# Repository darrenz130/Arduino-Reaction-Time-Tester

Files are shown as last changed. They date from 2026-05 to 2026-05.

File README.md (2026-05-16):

<h1>Arduino Reaction Time Tester PCB Design</h1>

<h2>Overview</h2>

<p>
This project is an Arduino-based reaction time testing system designed to measure human response speed with millisecond accuracy. The system uses LEDs as visual stimuli, a push button for user input, and a display to show reaction time results. The firmware is written in C++ and implemented on a custom PCB designed in KiCad.
</p>

<h2>Project Walkthrough</h2>

<h3>1. Breadboard Prototype</h3>

<p>
The initial version of the circuit was built and tested on a breadboard to validate functionality. This phase focused on verifying LED triggering, button input detection, and reaction timing accuracy.
</p>

<h3>2. Firmware Development</h3>

<p>
The system was programmed in C++ using the Arduino IDE. The code handles randomized LED stimulus timing, button press detection, and calculates reaction time in milliseconds using precise timing functions.
</p>

<h3>3. Schematic Design</h3>

<p>
A full circuit schematic was created in KiCad to define the electrical connections between the Arduino, LEDs, button, and display.
</p>

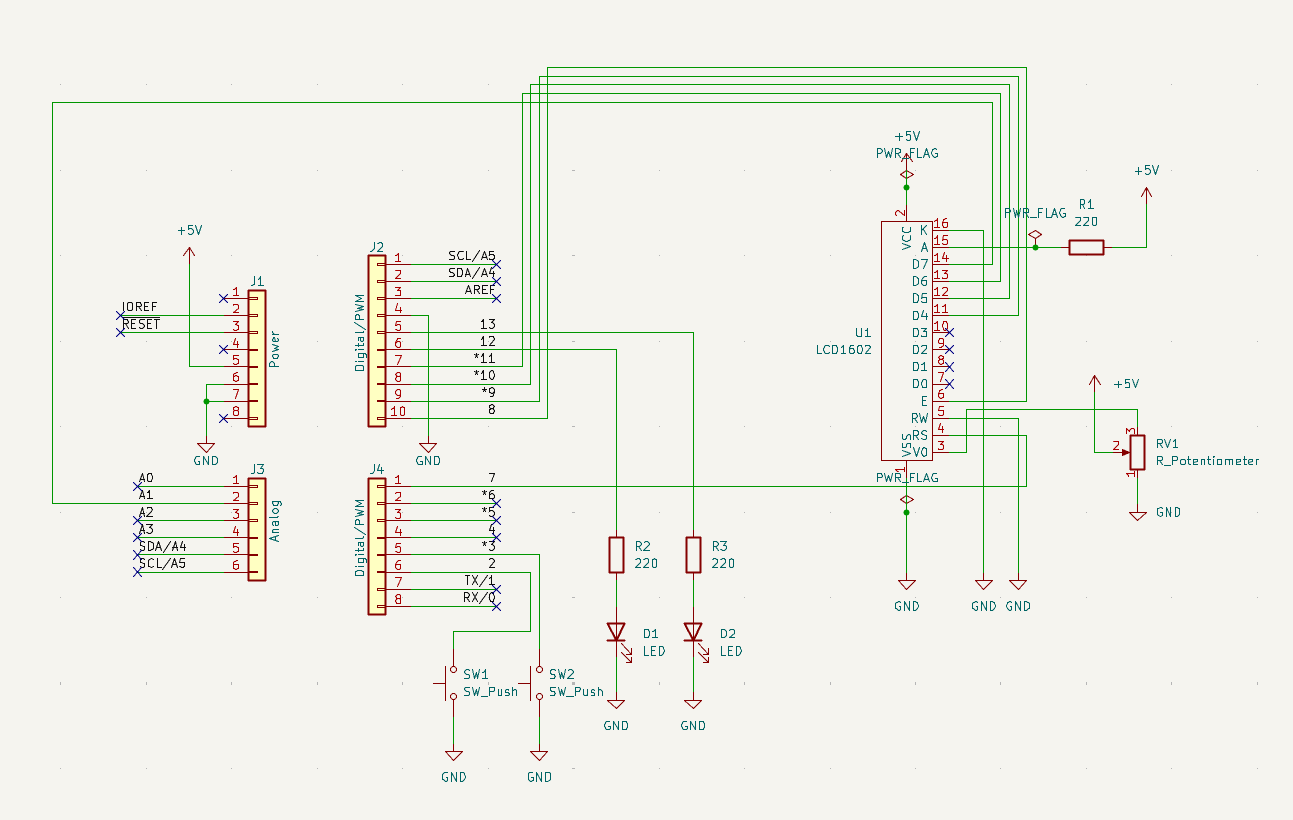
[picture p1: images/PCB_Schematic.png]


<h3>4. PCB Design</h3>

<p>
A custom PCB shield was designed in KiCad to replace the breadboard setup. This reduced wiring complexity, improved reliability, and created a compact final hardware design.
</p>

<p>
Custom footprints were created where required to match exact component dimensions. This included a potentiometer footprint due to the lack of an existing library part with the correct physical spacing, as well as a custom footprint for the display LED to ensure proper fit and alignment.
</p>

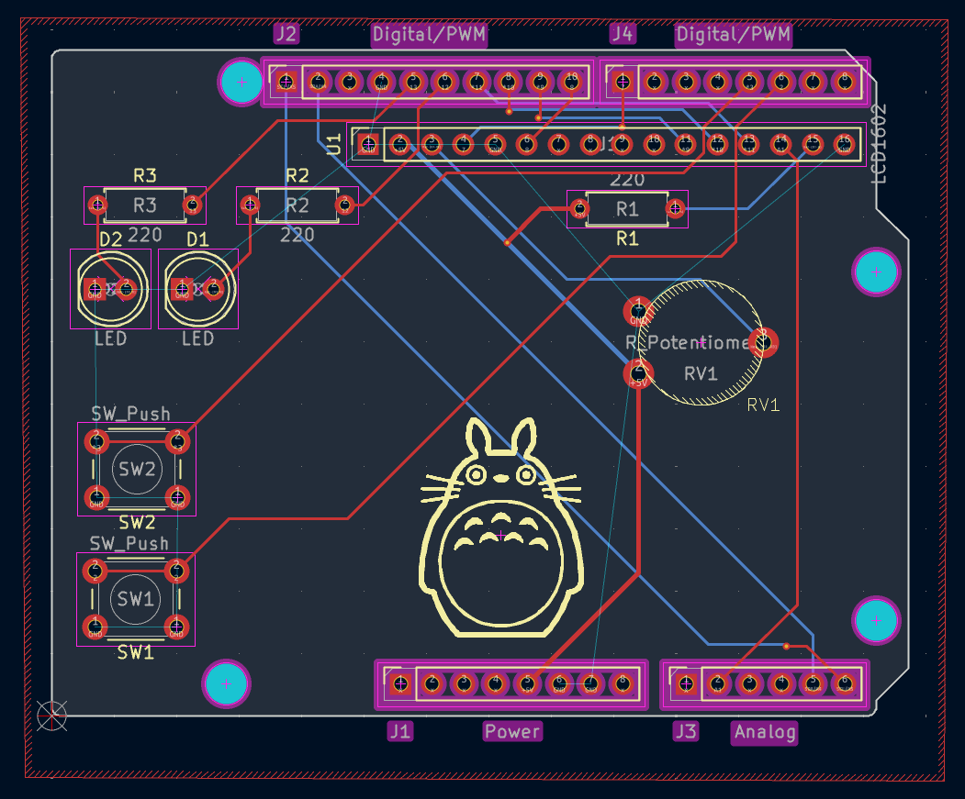
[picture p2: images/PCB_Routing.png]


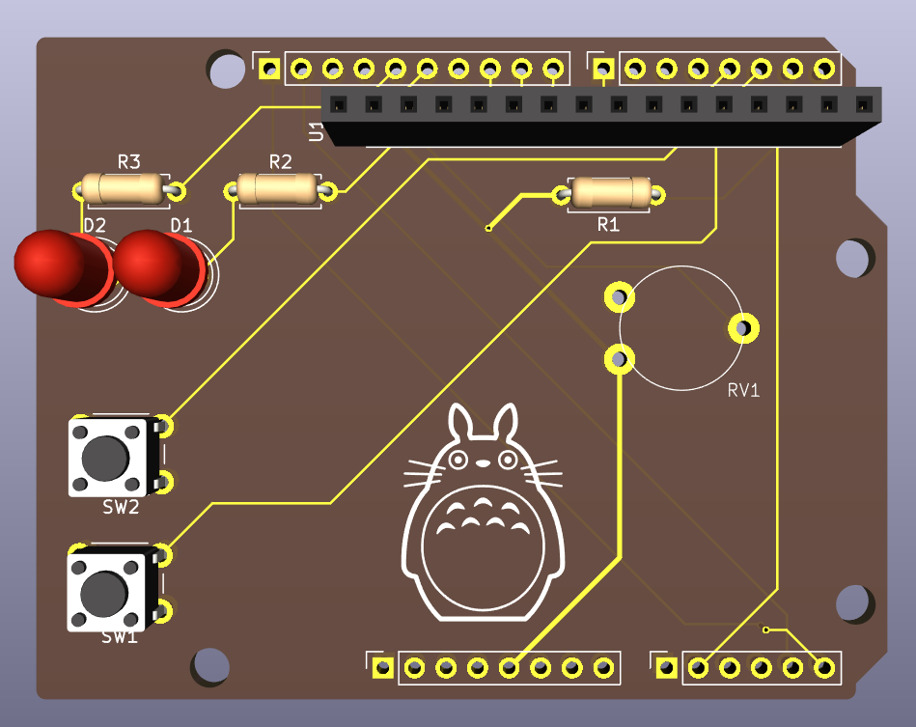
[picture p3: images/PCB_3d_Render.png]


<h2>Languages and Tools Used</h2>

<ul>
  <li>C++</li>
  <li>Arduino IDE</li>
  <li>KiCad (PCB Design)</li>
  <li>Breadboard Prototyping</li>
  <li>Multimeter / Circuit Debugging</li>
</ul>

<h2>Files in This Repository</h2>

<ul>
  <li><b>/firmware</b> → Arduino C++ code</li>
  <li><b>/pcb</b> → KiCad schematic and PCB files</li>
  <li><b>/images</b> → Project screenshots and renders</li>
</ul>

<h2>Demo</h2>

<p>
A short demonstration of the system in action:
<br>
<a href="https://youtu.be/OleBV9ndicw?si=QzNY1ve2LQjAxAnz">
Watch Demo Video
</a>
</p>

<h2>Key Features</h2>

<ul>
  <li>Millisecond-level reaction time measurement</li>
  <li>Randomized LED stimulus timing</li>
  <li>Custom PCB shield for improved reliability</li>
  <li>Fully tested breadboard prototype before final design</li>
</ul>

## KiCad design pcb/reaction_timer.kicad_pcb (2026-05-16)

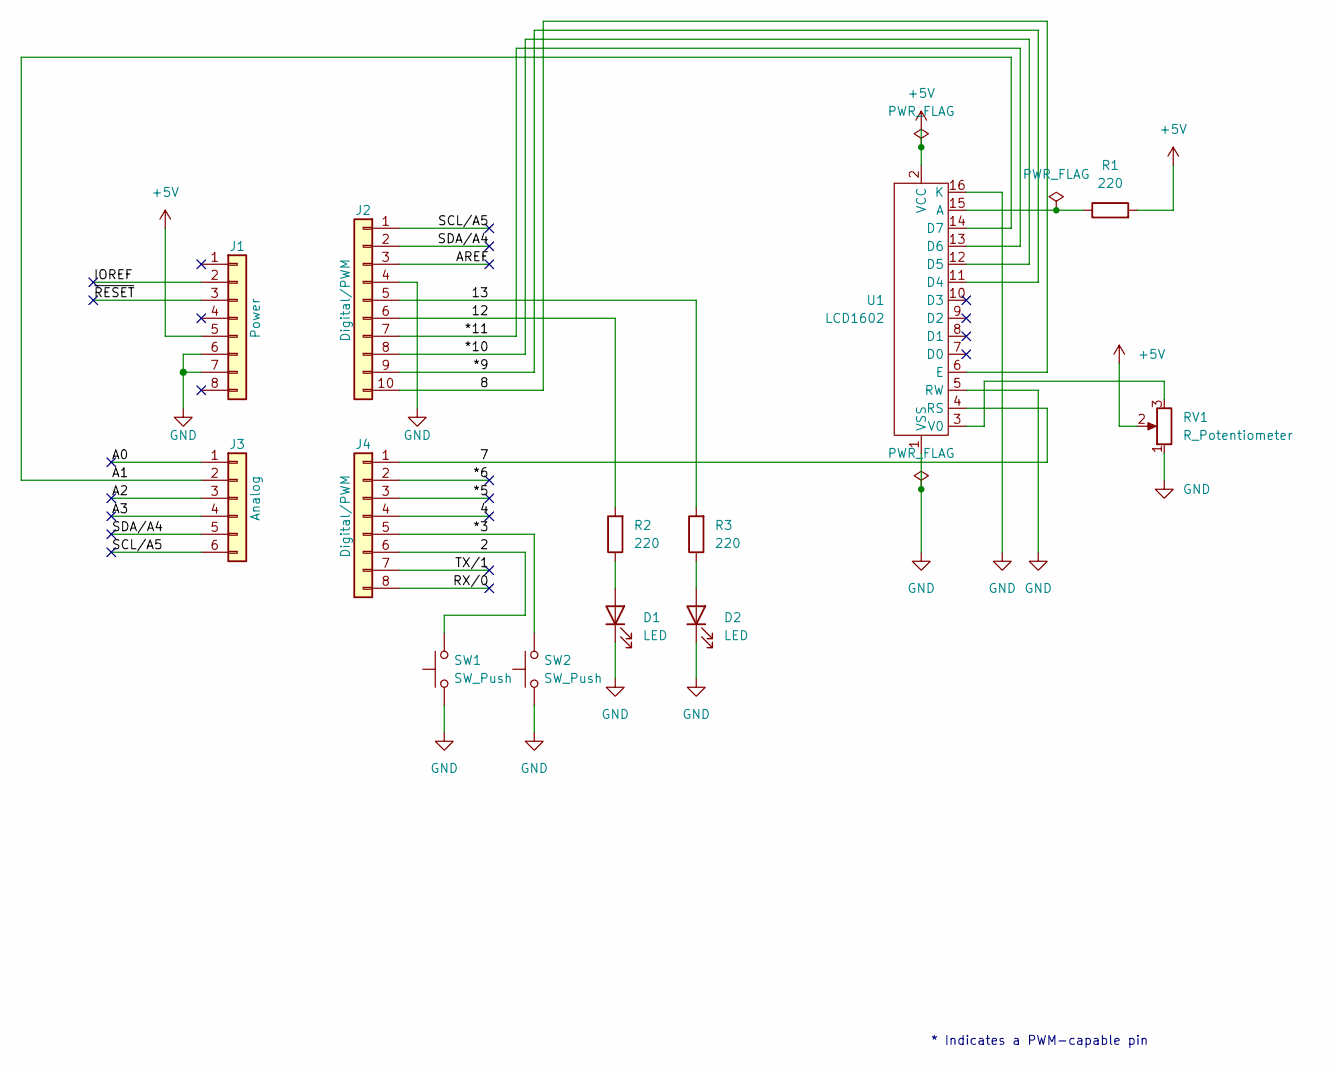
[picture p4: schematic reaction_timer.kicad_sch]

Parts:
D1, D2: LED; LED_D5.0mm
J1: Power; PinSocket_1x08_P2.54mm_Vertical
J2: Digital/PWM; PinSocket_1x10_P2.54mm_Vertical
J3: Analog; PinSocket_1x06_P2.54mm_Vertical
J4: Digital/PWM; PinSocket_1x08_P2.54mm_Vertical
R1, R2, R3: 220; R_Axial_DIN0207_L6.3mm_D2.5mm_P7.62mm_Horizontal
RV1: R_Potentiometer; 10k potentiameter
SW1, SW2: SW_Push; SW_PUSH_6mm
U1: LCD1602; PinSocket_1x16_P2.54mm_Vertical

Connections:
+5V: J1.5, R1.2, RV1.2, U1.2 (VCC)
/2: J4.6, SW1.2
/4: J4.4
/7: J4.1, U1.4 (RS)
/8: J2.10, U1.6 (E)
/12: J2.6, R2.2
/13: J2.5, R3.2
/*3: J4.5, SW2.2
/*5: J4.3
/*6: J4.2
/*9: J2.9, U1.11 (D4)
/*10: J2.8, U1.12 (D5)
/*11: J2.7, U1.13 (D6)
/A0: J3.1
/A1: J3.2, U1.14 (D7)
/A2: J3.3
/A3: J3.4
/AREF: J2.3
/IOREF: J1.2
/RX/0: J4.8
/SCL/A5: J2.1, J3.6
/SDA/A4: J2.2, J3.5
/TX/1: J4.7
/~RESET: J1.3
GND: D1.1 (K), D2.1 (K), J1.6, J1.7, J2.4, RV1.1, SW1.1, SW2.1, U1.1 (VSS), U1.5 (RW), U1.16 (K)
unnamed: D1.2 (A), R2.1
unnamed: D2.2 (A), R3.1
unnamed: R1.1, U1.15 (A)
unnamed: RV1.3, U1.3 (V0)

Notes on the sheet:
* Indicates a PWM-capable pin

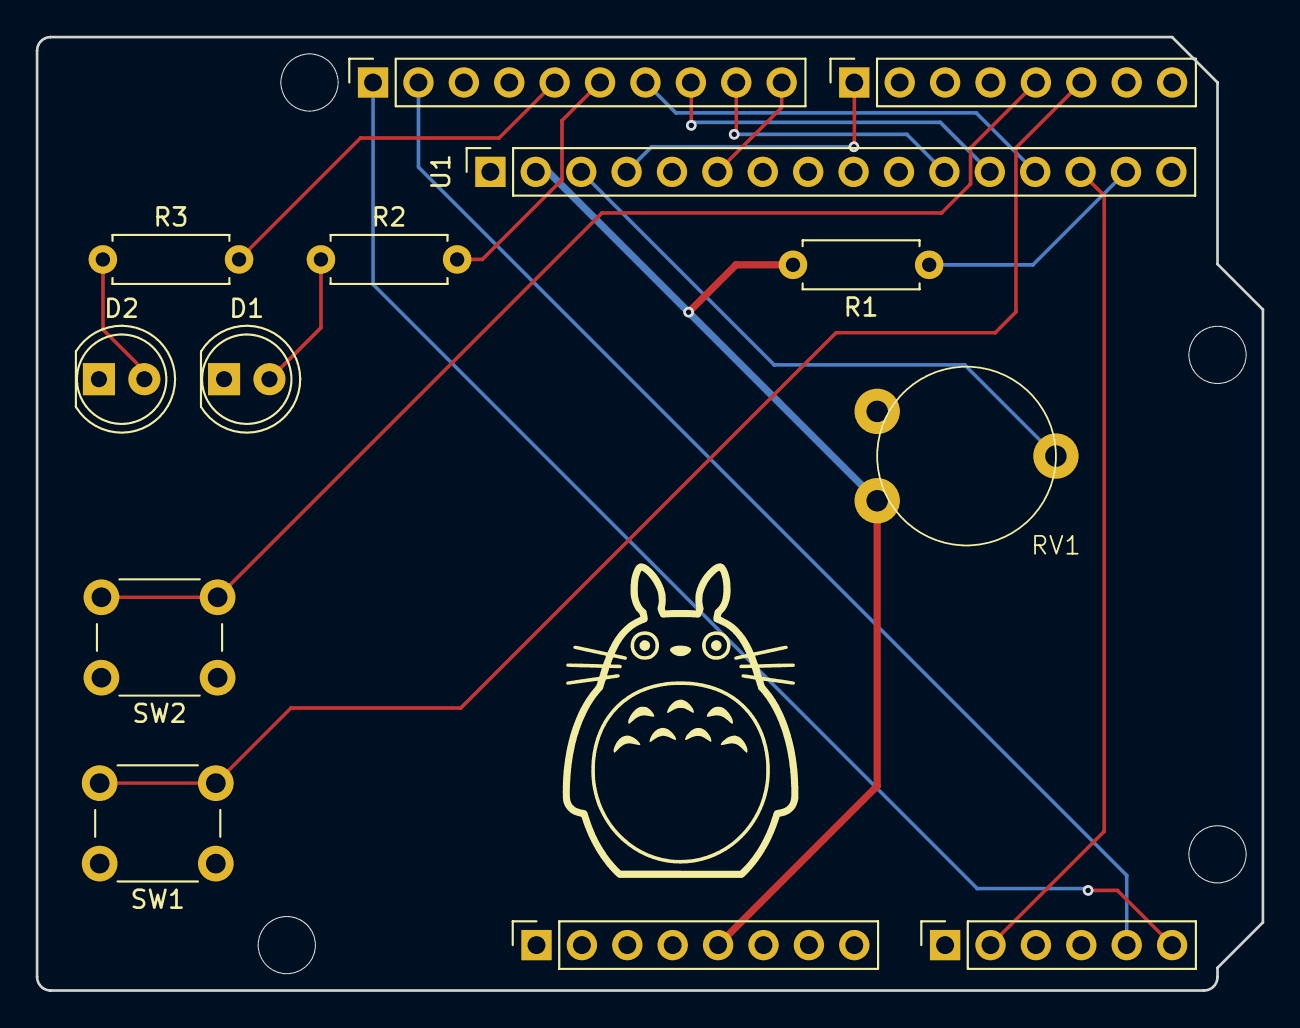
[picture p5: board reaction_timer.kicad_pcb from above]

Board: 2 copper layers, 68.6 x 53.3 mm, 17 parts (0 on the bottom side), 18 nets.

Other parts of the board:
MH1, MH2, MH3, MH4: MountingHole_3.2mm

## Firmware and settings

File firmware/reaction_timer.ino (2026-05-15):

#include <LiquidCrystal.h>

// LCD pins: RS, E, D4, D5, D6, D7
LiquidCrystal lcd(7, 8, 9, 10, 11, A1);

const int led_green = 13;
const int led_red = 12;
const int startButton = 2; 
const int clickButton = 3; 

unsigned long waitTime = 0;
unsigned long startTime = 0;
unsigned long reactionTime = 0;

// Define states
enum State {IDLE, WAITING, GREEN_ON, DONE};
State currentState = IDLE;

void setup() {
  pinMode(led_green, OUTPUT);
  pinMode(led_red, OUTPUT);
  pinMode(startButton, INPUT_PULLUP);
  pinMode(clickButton, INPUT_PULLUP);

  lcd.begin(16, 2);
  lcd.setCursor(0,0);
  lcd.print("Reaction Timer");
  lcd.setCursor(0,1);
  lcd.print("Press Start");
  
  randomSeed(analogRead(A0));
}

void loop() {  
  switch(currentState) {
    case IDLE:
      // Wait for start button to begin
      if (digitalRead(startButton) == LOW) {
        lcd.setCursor(0,1);
        lcd.print("Get Ready...   ");
        digitalWrite(led_red, HIGH);
        waitTime = random(1000, 5000); // 1-5 sec
        startTime = millis();
        currentState = WAITING;
        delay(50); // debounce
      }
      break;

    case WAITING:
      if(digitalRead(led_red) == HIGH && digitalRead(clickButton) == LOW){
        digitalWrite(led_red, LOW);
        lcd.setCursor(0,1);
        lcd.print("Too Early!     ");
        currentState = DONE;
        delay(200);
      }
      if (millis() - startTime >= waitTime) {
        digitalWrite(led_red, LOW);
        digitalWrite(led_green, HIGH); // stays on until click
        lcd.setCursor(0,1);
        lcd.print("Click!         ");
        startTime = millis(); // start measuring reaction
        currentState = GREEN_ON;
      }
      break;

    case GREEN_ON:
      // Wait until user presses click button
      if (digitalRead(clickButton) == LOW) {
        reactionTime = millis() - startTime;
        lcd.setCursor(0,1);
        lcd.print("Time: ");
        lcd.print(reactionTime);
        lcd.print(" ms   ");
        digitalWrite(led_green, LOW);
        currentState = DONE;
        delay(200); // debounce
      }
      break;

    case DONE:
      // Wait for user to press start to reset
      if (digitalRead(startButton) == LOW) {
        lcd.setCursor(0,1);
        lcd.print("Press Start    ");
        digitalWrite(led_red, LOW);
        digitalWrite(led_green, LOW);
        currentState = IDLE;
        delay(200); // debounce
      }
      break;
  }
}

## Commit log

2026-05-15 Create schematic
2026-05-16 Enhance PCB Design section with custom footprints info
    Added details about custom footprints created for components in PCB design.
2026-05-16 Update README with PCB design images
    Added images of PCB schematic, routing, and 3D render to README.
